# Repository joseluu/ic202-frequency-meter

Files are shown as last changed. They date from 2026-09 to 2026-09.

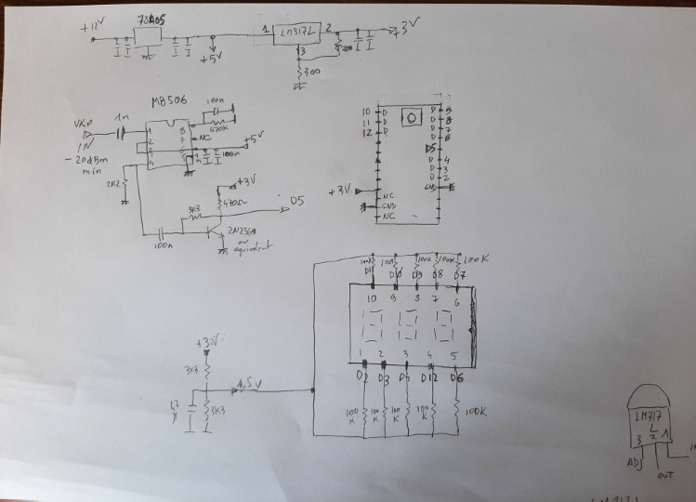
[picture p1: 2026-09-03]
docs/Schema_propre.jpg

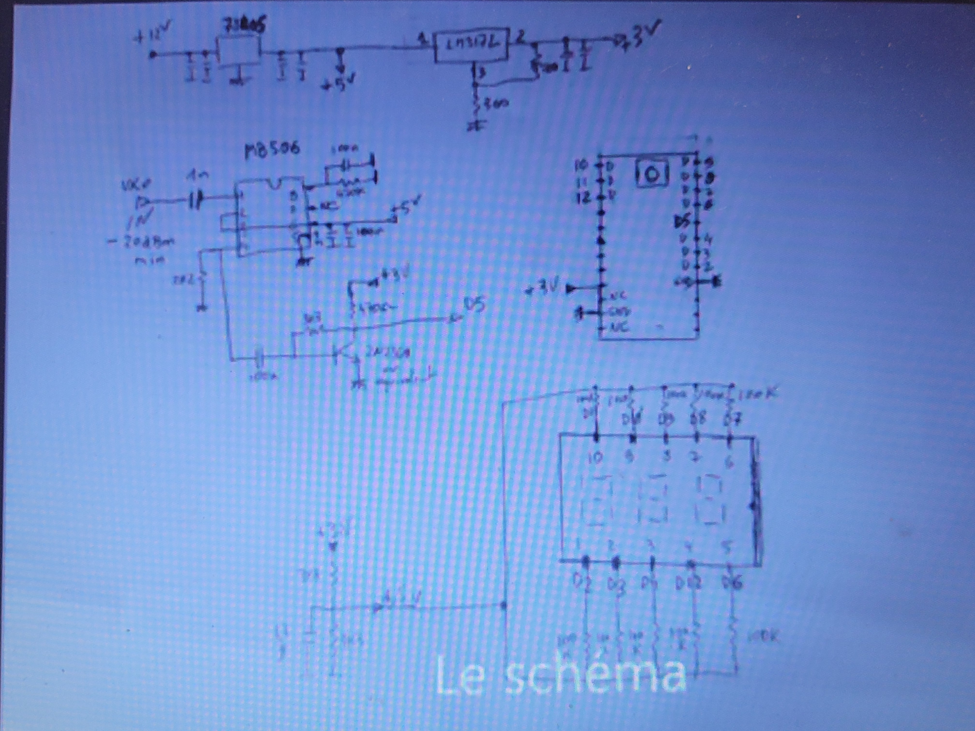
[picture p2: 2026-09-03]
docs/Schema.jpg

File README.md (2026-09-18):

# Fréquencemètre IC-202

Projet KiCad transcrit du schéma manuscrit, selon la description de
`docs/specifications.md`. Deux versions du schéma existent dans `docs/` :
`Schema.jpg`, la première photo, et `Schema_propre.jpg`, une reprise plus
lisible qui a servi à corriger plusieurs valeurs mal lues sur la première.

Chaîne de mesure : entrée RF → prédiviseur MB506 → étage de mise en forme à
transistor alimenté en 3 V → broche D5 d'un Arduino Pro Mini → afficheur LCD
3 digits 7 segments multiplexé, déporté au bout d'une nappe.

## Contenu

| Fichier | Rôle |
|---|---|
| `kicad/ic202-frequencemetre.kicad_pro` | Projet KiCad 10 |
| `kicad/ic202-frequencemetre.kicad_sch` | Schéma (feuille A3 unique) |
| `kicad/ic202-frequencemetre.kicad_pcb` | Carte, encore vide |
| `kicad/IC202.kicad_sym` | Symboles créés pour ce projet |
| `kicad/sym-lib-table` | Enregistrement de la bibliothèque de symboles `IC202` (portée projet) |
| `kicad/frequencemetre.pretty/` | Empreintes créées pour ce projet |
| `kicad/fp-lib-table` | Enregistrement de la bibliothèque d'empreintes `frequencemetre` (portée projet) |
| `kicad/ic202-frequencemetre.pdf` / `.svg` | Schéma exporté |
| `kicad/bom.csv` | Nomenclature |
| `kicad/erc.rpt` | Rapport ERC |
| `docs/Schema.jpg`, `docs/Schema_propre.jpg` | Schéma manuscrit d'origine et sa reprise lisible |
| `docs/LCD.png` | Fiche technique de l'afficheur LCD |

## État de vérification

- ERC : **0 erreur, 0 avertissement**.
- Netlist vérifiée broche à broche par export `kicadxml` après chaque retouche.
- `check_label_rotations.py` et `check_symbol_overlap.py` : OK.
- `lint_offgrid` : aucune coordonnée hors grille 1,27 mm.

## Organisation du schéma

La disposition reprend celle du schéma papier : alimentation en bandeau haut,
prédiviseur à gauche, mise en forme au centre, Arduino à droite, afficheur en
bas à droite. Les liaisons courtes à l'intérieur d'un bloc sont des fils ; les
rails d'alimentation et les signaux entre blocs passent par étiquettes de net.

## Règles de lisibilité appliquées

Les directives du skill
[kicad-schematic-readability](https://github.com/joseluu/kicad-schematic-readability)
sont respectées, et vérifiées par deux scripts locaux au poste de travail :

```
python check_label_rotations.py  .../ic202-frequencemetre.kicad_sch   # OK
python check_symbol_overlap.py   .../ic202-frequencemetre.kicad_sch   # OK
```

- **GND indépendants** : aucun fil de masse ne traverse la feuille, chaque
  composant a son propre stub GND.
- **Alimentation en haut, GND en bas** : les découplages ont leur broche
  positive vers le haut et leur masse vers le bas. Les connecteurs suivent la
  même règle : `J1` porte le +12 V en haut et la masse en bas, `J2` a son
  blindage dirigé vers le bas. Les deux ont été retournés par un miroir, ce qui
  inverse l'ordre des broches sans déplacer la broche de signal.
- **Signaux de gauche à droite** : entrée RF à gauche, progression vers
  l'Arduino puis l'afficheur à droite.
- **Étiquettes réservées aux signaux utiles** : rails, RF_IN, D5_SIG,
  VLCD_MID et les dix lignes LCD_COM/LCD_SEG. SW1 et SW2 sont marquées non
  connectées plutôt qu'étiquetées, faute d'utilité une fois flottantes.
- **Aucun chevauchement de symboles.**

### Placement des repères et valeurs

- **Circuits intégrés rectangulaires** (`U1`, `U2`, `U3`, `A1`, `DS1`) : repère
  et valeur au centre du rectangle, l'intérieur étant libre depuis le masquage
  des noms de broches. Ces champs ne portent aucun `justify`, le défaut centré
  étant celui recherché.
- **Résistances** : valeur au centre du corps et repère sur la ligne au-dessus,
  les deux suivant l'orientation du composant. Pour une résistance verticale le
  texte se lit de bas en haut, donc la ligne au-dessus est celle de gauche.
- **Condensateurs** : repère et valeur de part et d'autre du fil du symbole,
  juste sous les armatures. Le cas vertical exige un `justify` explicite, sinon
  le texte traverse le fil. Le cas horizontal sépare par la hauteur.

### Convention d'orientation des étiquettes

Une étiquette de net a besoin des **deux** informations, et elles doivent être
cohérentes entre elles :

- l'**angle** donne l'axe de lecture, et sert d'indicateur de direction pour le
  script de contrôle ;
- le **`justify`** décide de quel côté du point d'ancrage le texte est posé.
  C'est lui seul que KiCad utilise pour placer le texte.

| Angle | `justify` | Le texte se pose |
|---|---|---|
| 0 | `left bottom` | à droite de l'ancrage |
| 90 | `left bottom` | au-dessus |
| 180 | `right bottom` | à gauche |
| 270 | `right bottom` | en dessous |

Le second mot `bottom` décale le texte perpendiculairement, pour qu'il ne soit
pas posé sur le fil.

**Piège n° 1 : pas de `justify` du tout.** Le défaut de KiCad est *centré*, donc
l'étiquette chevauche son propre point de connexion et le numéro de broche.
C'est visible surtout sur les étiquettes posées directement sur une broche, les
étiquettes en bout de stub ayant de la place autour. Chaque étiquette doit
porter un `justify` explicite.

**Piège n° 2 : `lint_schematic_cosmetic` passe `orient_labels`.** Cette passe du
serveur MCP produit une orientation à 180° de la bonne. Ne pas la relancer sur
ce schéma. Si c'est fait par erreur, réappliquer la table ci-dessus.

**Autre piège.** Dans un champ `property` d'un symbole tourné à 90°, l'angle
est relatif au symbole : il faut écrire 270 pour obtenir un texte horizontal.
C'est le cas des repères de `R7`..`R16`.

### Alimentation

`J1` (+12 V) → `U1` AMS1117-5.0 → +5 V → `U2` AMS1117 (ADJ) → +3 V.
Découplage 100 nF + 10 µF sur chacun des trois rails.

Les deux régulateurs sont en boîtier CMS SOT-223, choisis dans le stock
PartsBox de l'utilisateur plutôt que les L7805/LM317L d'origine (traversants,
non tenus en stock CMS) : mêmes coordonnées de broches, seule leur
numérotation change. Sur `U1`, l'entrée devient la broche 3 (VI) et la
sortie la broche 2 (VO) — sur `U2`, `1`=ADJ, `2`=VO, `3`=VI comme
auparavant, l'architecture (référence 1,25 V, pont diviseur) étant la même
famille que le LM317.

Le +3 V est réglé par `R1` (220 R, VO→ADJ de `U2`) et `R2` (300 R,
ADJ→GND) :

    Vout = 1,25 x (1 + 300/220) = 2,95 V

C'est proche de la tension de service du LCD (3,0 V), indiquée sur sa fiche.
Ce pont n'a pas changé de valeur : l'AMS1117 ajustable utilise la même
référence 1,25 V que le LM317L qu'il remplace.

`#FLG01` et `#FLG02` sont les PWR_FLAG des rails +12 V et GND, qui ne sont
alimentés que par un connecteur.

`J1` est un connecteur 4 broches (header 2,54 mm) : les broches 1 et 2,
adjacentes, portent toutes deux le +12 V ; les broches 3 et 4, adjacentes,
portent toutes deux le GND. Le doublement de chaque broche répartit le
courant d'alimentation sur deux points de contact.

### Prédiviseur MB506

`U3` est le Fujitsu **MB506PF**, boîtier CMS SOP-8 (208 mil, empreinte
`Package_SO:SOIC-8_5.3x6.2mm_P1.27mm`), en remplacement du MB506 traversant
DIP-8 d'origine — même brochage 1-8 (IN, VCC, SW1, OUT, GND, SW2, NC, /IN),
choisi dans le stock PartsBox de l'utilisateur.

- `J2` entrée RF, terminaison `R3` 51 R, liaison capacitive `C7` 1 nF vers IN (broche 1).
  Pas de connecteur SMA monté : un mini câble coaxial est soudé directement
  sur deux pastilles (`TestPoint:TestPoint_2Pads_Pitch2.54mm_Drill0.8mm`,
  pas 2,54 mm, perçage 0,8 mm) — âme sur la pastille 1 (IN), blindage sur
  la pastille 2 (GND).
- Entrée complémentaire /IN (broche 8) : découplée à la masse par `C8` 100 nF,
  et polarisée par `R20` 470 kΩ vers GND. C'est le réseau optionnel repéré sur
  le schéma relu (voir « Hypothèses de transcription ») ; il fixe le point de
  repos de l'entrée complémentaire quand le MB506 est piloté en simple
  extrémité (un seul signal sur IN, ~IN laissée au repos).
- VCC (broche 2) en +5 V, découplé par `C9` 100 nF.
- Sortie OUT (broche 4) : pull-down `R19` (2K2) vers GND, en parallèle de la
  liaison capacitive vers l'étage de mise en forme. C'est une terminaison
  usuelle pour une sortie de type collecteur ouvert / ECL.
- Broche 7 (NC) marquée non connectée. La datasheet Fujitsu ne lui donne
  aucune fonction : le rapport de division est fixé uniquement par SW1 et
  SW2, il n'y a pas de troisième entrée de sélection.
- SW1 (broche 3) et SW2 (broche 6) reliées au rail +5 V **à travers un
  cavalier à souder fermé** (`JP11` sur `MB506_SW1`, `JP12` sur `MB506_SW2`,
  empreinte `Jumper:SolderJumper-2_P1.3mm_Bridged_Pad1.0x1.5mm`).

D'après la table du constructeur (H = VCC, L = ouvert), SW1 et SW2 au niveau H
donnent le rapport **1/64**, comportement par défaut de cette carte :

| SW1 | SW2 | Division |
|---|---|---|
| ouvert | ouvert | 1/256 |
| ouvert | +5 V | 1/128 |
| +5 V | ouvert | 1/128 |
| **+5 V** | **+5 V** | **1/64** |

Le schéma d'origine prévoyait un connecteur `J3` pour choisir le rapport ; il
n'apparaît plus sur le schéma relu, qui laisse SW1/SW2 flottants (1/256 par
défaut). À la demande explicite, les deux broches sont ici reliées au +5 V
pour fixer la division à 1/64. `JP11`/`JP12` remplacent ce sélecteur : livrés
fermés, ils conservent le 1/64 ; couper `JP11` **ou** `JP12` au cutter remet
la broche correspondante en l'air (niveau L) et donne 1/128, couper les deux
donne 1/256. Un coup de fer à souder revient en arrière.

### Mise en forme vers D5

`Q1` est le NPN RF **2SC5551AE-TD-E** (onsemi), boîtier CMS SOT-89
(30 V, 300 mA, fT = 3,5 GHz), en remplacement du 2N2369 traversant (TO-18,
fT ≈ 500 MHz) — choisi dans le stock PartsBox de l'utilisateur, largement
assez rapide pour ce rôle. Le brochage réel (1 = base, 2 = collecteur sur
la languette, 3 = émetteur) ne correspond pas à l'ordre du symbole générique
KiCad `Q_NPN_BEC` (broche 2 = émetteur, broche 3 = collecteur) : le symbole a
donc été remplacé par `Q_NPN_BCE` (broche 2 = collecteur, broche 3 =
émetteur), qui a la même géométrie de broches — seul l'étiquetage
broche/fonction change, le câblage existant reste intact — pour que la
numérotation corresponde à celle de l'empreinte SOT-89.

Sortie ECL du MB506 → `C10` 100 nF → base de `Q1`. `R4` 3,3 kΩ relie
la base au collecteur (contre-réaction continue, pas une résistance série vers
la masse comme dans une première version du schéma). Émetteur à la masse,
collecteur tiré au +3 V par `R6` 470 Ω, et c'est ce nœud collecteur qui attaque
D5. Le point de repos de `Q1` s'auto-régule par cette contre-réaction plutôt
que par un pont de base classique. Le niveau logique vu par l'Arduino est donc
bien du 3 V, d'où la présence du second régulateur (`U2`).

### Arduino

L'Arduino Pro Mini est la version **3,3 V / 8 MHz**, alimentée sur sa broche VCC
depuis le rail +3 V (le régulateur de la carte est contourné, RAW non connectée).
L'ATmega328P à 8 MHz fonctionne sans réserve jusqu'à 2,7 V.

D13 est laissé libre à cause de la LED intégrée. TXO/RXI restent disponibles
pour la programmation par le connecteur FTDI de la carte.

**Montage sur picots.** Le Pro Mini n'est pas soudé directement : il se
branche sur deux barrettes de picots femelles soudées sur le PCB principal
(empreinte `frequencemetre:Arduino_Pro_Mini_Header_2x12`). Il se trouve donc surélevé
par rapport à la carte, et le volume dégagé en dessous est disponible pour
d'autres composants. Cette empreinte ne modélise que les deux courtyards des
barrettes (pas de contour de carte complet ni de courtyard unique englobant
tout le module), justement pour ne pas signaler ce volume comme occupé.

Géométrie vérifiée contre l'empreinte open source
[`Arduino_Pro_Mini_Socket`](https://github.com/Alarm-Siren/arduino-kicad-library)
(2 rangées de 12 broches au pas de 2,54 mm, 15,24 mm entre rangées) : 24
broches au total, pas de connecteur de programmation FTDI modélisé. Les
broches A4/SDA et A5/SCL du Pro Mini réel ne sont pas sur ces barrettes — ce
sont des pastilles au dos du module, atteignables seulement par un fil volant
— et ont été retirées du symbole `IC202:Arduino_Pro_Mini`, qui ne comptait
d'ailleurs déjà aucune connexion sur ces deux broches.

### Afficheur LCD

`docs/LCD.png` donne la fiche du composant :

| Caractéristique | Valeur |
|---|---|
| Technologie | TN, polariseur réflectif positif |
| Multiplexage | 1/4 duty, 1/2 bias |
| Tension de service | 3,0 V |
| Angle de lecture | 6 heures |
| Broches | 10, au pas de 2,00 mm |

Référence commerciale :
<https://fr.aliexpress.com/item/1005003745628043.html>

Le 1/4 duty impose **4 communs**, et les 10 broches se répartissent donc en
4 communs plus **6 segments**. Cela adresse 4 × 6 = 24 segments, dont 21 pour
les trois chiffres.

C'est un afficheur à cristaux liquides : il ne consomme aucun courant et ne
supporte pas de tension continue permanente, qui le détruirait par
électrolyse. Il n'y a donc **pas de résistance de limitation** ; l'attaque se
fait en alternatif, par inversion de polarité à chaque trame.

**Attaque en 1/2 bias par tri-état.** Chaque ligne a besoin de trois niveaux :
0 V, 1,5 V et 3 V. Les broches de l'Arduino en fournissent deux, et le
troisième vient de la mise en haute impédance : la ligne rejoint alors la
référence à mi-tension `VLCD_MID` à travers sa résistance de 100 kΩ.

| Élément | Rôle |
|---|---|
| `R7`..`R16` (100 kΩ) | une par ligne, vers `VLCD_MID` |
| `R17`, `R18` (10 kΩ) | pont générant `VLCD_MID` = 3 V / 2 |
| `C12` (1 µF) | découplage de la référence |

Le pont est dix fois plus raide que les résistances de ligne, pour que la
référence ne bouge pas quand plusieurs broches commutent.

**Cavaliers de coupure devant `J4`.** Un cavalier à souder fermé par défaut
(`JP1`..`JP10`, empreinte `Jumper:SolderJumper-2_P1.3mm_Bridged_Pad1.0x1.5mm`)
est inséré en série entre chaque ligne (`R7`..`R16`) et sa broche de `J4` —
un par ligne LCD. Chaque ligne passe donc par deux nœuds électriques
distincts : le nœud côté Arduino/résistance (nom de net inchangé,
`LCD_COM1`..`LCD_SEG6`) et le nœud côté `J4` (nommé explicitement
`J4_COM1`..`J4_SEG6`), reliés par le cavalier. Fermés (comportement par
défaut, pont de cuivre déjà présent sur l'empreinte), la liaison vers la
nappe LCD est normale ; les couper au cutter isole la carte de la nappe —
utile pour tester l'étage Arduino/résistances seul avant de raccorder
l'afficheur. Un coup de fer à souder rétablit ensuite la liaison.

**Deux bugs de câblage trouvés et corrigés après coup, à l'occasion d'une
tentative de routage** (voir plus bas) :

1. Les 10 fils reliant chaque cavalier à sa broche de `J4` passaient par un
   point de coude intermédiaire à une abscisse commune (`x=330.2`) pour
   rester orthogonaux. Plusieurs de ces segments verticaux se chevauchaient
   partiellement sur cette même abscisse (les nappes de lignes LCD ont des
   pas différents côté résistances — 5,08 mm — et côté `J4` — 2,54 mm — donc
   leurs coudes intermédiaires ne tombent pas aux mêmes hauteurs), ce qui a
   **court-circuité entre elles plusieurs lignes LCD** (`COM2`-`COM3`-`COM4`-`SEG1`
   d'un côté, `SEG3`-`SEG4` de l'autre). L'ERC ne signalait qu'un avertissement
   discret (« multiple_net_names »), pas une erreur — c'est une relecture du
   netlist exporté par `kicad-cli` (source de vérité) qui a révélé l'ampleur
   réelle du problème. Corrigé en remplaçant les 10 chemins coudés par un
   fil diagonal unique par ligne (pas de point partagé entre lignes
   différentes, donc aucun risque de chevauchement accidentel).
2. Après correction du point 1, le nom de net explicite (`J4_COM1` etc.) a
   dû être ajouté sur chaque broche de `J4` : sans lui, `sync_schematic_to_board`
   (l'outil MCP qui importe le schéma dans le PCB) n'arrivait pas à
   résoudre les nets anonymes auto-générés par KiCad (`Net-(J4-Pin_X)`) et
   laissait ces broches et celles des cavaliers **sans net du tout** côté
   PCB — invisibles pour le ratsnest et l'autorouteur, silencieusement, sans
   qu'aucun outil ne le signale comme une erreur. Un nom de net explicite
   sur chaque broche contourne cette limite.

**Affectation des broches de l'Arduino :**

| Broche | Ligne LCD |
|---|---|
| D5 | entrée de comptage depuis l'étage transistor |
| D2, D3, D4, D6 | COM1, COM2, COM3, COM4 |
| D7, D8, D9, D10, D11, D12 | SEG1 à SEG6 |

**Liaison par nappe.** Le LCD est déporté au bout d'une nappe de 10
conducteurs. `J4` (header mâle au pas de 2,54 mm) est le seul connecteur
présent sur la carte ; `DS1`, l'afficheur, n'est **pas monté sur ce PCB**,
il se trouve à l'autre extrémité du câble. Le symbole `DS1` est marqué
« hors carte » (`on_board: no`) : il reste dans le schéma et la nomenclature
pour documenter le système complet, mais `sync_schematic_to_board` ne lui
crée pas d'empreinte sur cette carte.

## Intention de conception pour le placement/routage

Le schéma porte, en plus de la connectivité, une propriété masquée
`Placement` sur chaque composant dont la position physique finale importe
au-delà du simple raccordement électrique — suivant le skill Claude Code
`conception-electronique-kicad`. Cette propriété n'apparaît pas sur le
schéma ; elle se lit via `get_schematic_component` ou en filtrant le
`.kicad_sch` sur `(property "Placement"`. **Elle ne s'applique pas toute
seule** : au moment du placement/routage, il faut demander explicitement de
la respecter.

**Découplage documenté** (préfixe `LOCAL`) :

| Réf. | Rôle |
|---|---|
| `C1`, `C2` | HF / bulk BF, entrée `J1` et broche 3 (VI) de `U1` |
| `C3`, `C4` | HF / bulk BF, nœud +5 V partagé broche 2 (VO) de `U1` / broche 3 (VI) de `U2` |
| `C5`, `C6` | HF / bulk BF, broche VO (sortie) de `U2` |
| `C9` | HF, broche VCC de `U3` |
| `C8` | HF de la broche ~IN (signal, pas alimentation) de `U3`, avec `R20` |
| `C11` | HF du rail +3 V près de `R6`, point le plus éloigné de `U2` |
| `C12` | référence `VLCD_MID`, point milieu du pont `R17`/`R18` |

Vérification faite : les trois circuits intégrés actifs (`U1`, `U2`, `U3`)
ont chacun un découplage local documenté sur leur(s) broche(s)
d'alimentation. `A1` (Arduino Pro Mini) n'est pas inclus dans cette
vérification : c'est un module complet avec son propre découplage embarqué,
pas un CI nu à décrire ici.

**Boucles critiques documentées** (préfixe `LOOP CRITIQUE`, hors
découplage) :

- `J2`-`R3`-`C7` → broche IN de `U3` : chemin RF d'entrée, jusqu'à 2,4 GHz,
  surface minimale impérative.
- `U3`(OUT)-`R19`-`C10`-`R4`-`R6`-`Q1` → `D5_SIG` (broche D5 de `A1`) : chemin
  de comptage, le signal que l'instrument existe pour mesurer — à éloigner
  des sources de bruit.

### Placement initial (fait)

Carte **80 × 50 mm**, paysage (hauteur réduite de 70 à 50 mm après le
passage aux boîtiers CMS ci-dessous, qui a libéré de la place). Emplacements
imposés par l'utilisateur :

- `J1` (+12 V IN) : bord haut, au milieu, rangée de broches **parallèle**
  au bord (rotation 90° par rapport à l'orientation par défaut du
  footprint, qui les mettait perpendiculaires).
- `J2` (RF IN, coax à souder) : bord gauche, rangée de broches parallèle au
  bord (même correction de rotation).
- `J4` (nappe LCD, header 2,54 mm) : bord droit.
- `A1` (Arduino Pro Mini sur picots) : décalé de 3 mm vers la gauche par
  rapport au premier placement, toujours à droite et proche de `J4`,
  orientation paysage, extrémité USB/FTDI côté gauche (rotation 90°, vérifiée
  par la mesure des pads comme au premier placement).
- `R7`..`R16` (échelle de polarisation LCD) : **sous `A1`**, dans le volume
  dégagé entre les deux barrettes de picots — l'empreinte de `A1` ne porte
  que les deux courtyards des barrettes (voir « Arduino » ci-dessus), donc
  cet espace n'est pas signalé occupé.

L'orientation « parallèle au bord le plus proche » pour `J1`/`J2` est
désormais une règle par défaut du skill `kicad-pcb-placement` : elle
s'applique à tout connecteur proche d'un bord, sauf orientation contraire
explicitement demandée.

Le reste (bloc d'alimentation, chaîne RF/prédiviseur, chemin de comptage,
cavaliers `JP1`-`JP10`, `R17`/`R18`/`C12`) est réparti par proximité en
suivant les groupes `Placement` du schéma. Vérifié via `run_drc`
(kicad-cli, source de vérité du projet) : **0 erreur**, 3 avertissements
cosmétiques silkscreen. Méthode suivie : skill Claude Code
`kicad-pcb-placement`.

### Routage (fait)

Autoroutage via Freerouting (`autoroute`, 2 couches F.Cu/B.Cu) sur ce
placement : **16,5 s**, 278 pistes + 29 vias. Deux passes de nettoyage
après coup :

- 11 pistes exportées à 0,15 mm par le pipeline KiCad→DSN→Freerouting alors
  que la carte impose 0,2 mm minimum (limite connue de ce pipeline,
  reproductible même en relançant l'autoroutage plusieurs fois de suite —
  ne se corrige pas tout seul). Corrigées une par une : piste supprimée puis
  retracée au même endroit avec une largeur explicite de 0,2 mm.
- Un essai de placement alternatif via l'outil externe **FD-Autoplacer**
  (`github.com/joseluu/FD-Autoplacer`, optimisation par descente de
  gradient) a été comparé sur ce même schéma : passage clone → exécution →
  import direct, sans succès retenu (chevauchement de courtyard réel,
  plusieurs composants débordant du bord de carte) — le placement à la main
  ci-dessus a été conservé.

Résultat final vérifié via `run_drc` : **0 erreur**, 10 avertissements
cosmétiques (7 vias non connectées des deux côtés, 1 chevauchement
silkscreen, 2 silkscreen sur cuivre).

### Bug critique trouvé et corrigé après coup : broches actives sans net

En inspectant le PCB routé, une broche visiblement connectée à trop
d'endroits (broche 1 de `U3`) a révélé un bug bien plus large : **5 nets
sans label explicite** (`Net-(U3-IN)`, `Net-(U3-OUT)`, `Net-(U3-~{IN})`,
`Net-(Q1-B)`, `Net-(U2-ADJ)`) — électriquement valides au niveau du schéma,
l'ERC ne signale rien — mais que `sync_schematic_to_board` échoue à
résoudre silencieusement, laissant les broches concernées **sans net du
tout côté PCB**. Conséquence réelle : la sortie du prescaler (`U3` OUT) et
la base de `Q1` n'ont jamais été reliées à la chaîne de comptage, sur les
deux cartes, malgré un DRC à 0 erreur — une broche sans net n'ayant par
ailleurs aucune obligation de clearance, ce qui explique l'apparence de
connexion multiple constatée.

Corrigé : les 5 nets renommés explicitement (`MB506_IN`, `MB506_OUT`,
`MB506_NIN`, `Q1_BASE`, `U2_ADJ`), resynchronisés vers les deux PCB, la
règle de clearance globale remontée de 0 mm (!) à 0,2 mm — qui a d'ailleurs
mis au jour des croisements de pistes que le clearance nul masquait — puis
carte principale entièrement reroutée : **0 erreur `run_drc`** au final
(327 pistes, 40 vias, même limite de 0,15 mm sur quelques pistes corrigée
comme précédemment). Règle ajoutée au skill `conception-electronique-kicad`
pour détecter ce cas systématiquement avant tout premier routage.

**Piège outil découvert à cette occasion :** `check_courtyard_overlaps`
(MCP) évalue le chevauchement de courtyard d'une empreinte à partir de sa
*bounding box globale*, pas des polygones réels — pour une empreinte à
plusieurs rectangles de courtyard disjoints comme celle de `A1` (justement
conçue pour laisser un volume libre au milieu), l'outil signale à tort un
chevauchement dès qu'un autre composant entre dans cette bounding box, y
compris pile au centre du volume libre. Vérifié en plaçant une résistance
au centre exact de `A1` et en comparant : `check_courtyard_overlaps` la
signale en conflit, `run_drc` (qui lit les vrais polygones KiCad) ne
signale rien. Pour toute empreinte de ce genre, se fier à `run_drc`, pas à
`check_courtyard_overlaps`.

## Hypothèses de transcription

La photo du schéma manuscrit n'est pas assez nette pour toutes les annotations.
Les points suivants ont été déduits ; ils sont à confronter à l'original.

| Élément | Retenu | Raison |
|---|---|---|
| `Q1` | 2N2369 | Lecture la plus probable de l'annotation ; transistor de commutation rapide cohérent avec l'usage. Tout NPN rapide équivalent convient. |
| `R17`, `R18` | 3,3 kΩ chacune | Valeur clairement lisible sur le schéma relu. |
| Affectation des 10 broches de `DS1` | 1..4 = COM1..COM4, 5..10 = SEG1..SEG6 | La fiche donne le nombre de broches et le multiplexage, pas leur ordre. **À confirmer avant fabrication.** |

Le schéma manuscrit relu (`docs/Schema_propre.jpg`) est nettement plus lisible
que la première photo et a permis de corriger plusieurs valeurs mal lues, ainsi
que d'ajouter des composants absents de la première transcription. Le tableau
ci-dessous liste les changements :

| Élément | Ancienne valeur | Valeur corrigée |
|---|---|---|
| `R1` | 100 R | 220 R |
| `R2` | 160 R | 300 R |
| `R6` | 1 k | 470 R |
| `C8` | 1 n | 100 n |
| `R17`, `R18` | 10 k | 3,3 k |
| ancien `R5` (100 k, base→GND) | présent | supprimé, absent du schéma relu |
| ancien `J3` (sélecteur SW1/SW2) | présent | supprimé, remplacé par les cavaliers `JP11`/`JP12` (fermés = 1/64) |
| `R19` (2K2, OUT MB506→GND) | absent | ajouté |
| `R4` | 1 k, en série cap→base | 3,3 k, en contre-réaction base→collecteur |
| `R20` (470 kΩ, broche 8 ~IN→GND) | absent | ajouté |

Deux de ces corrections ont été apportées directement dans KiCad par
l'utilisateur puis relues par la suite : le rebranchement de `R4` en
contre-réaction base→collecteur (la première transcription le plaçait par
erreur en série entre `C10` et la base), et l'ajout de `R20`, le réseau
repéré près de la broche complémentaire (~IN, broche 8) du MB506, qui polarise
cette broche vers la masse quand le composant est piloté en entrée simple.

## Ce qui reste à faire

1. **Obtenir la table de correspondance segments du LCD**, c'est-à-dire quel
   couple (COM, SEG) allume quel segment de quel chiffre. Elle n'est pas dans
   la fiche et conditionne le firmware. Sans elle, on peut router la carte mais
   pas afficher un chiffre juste.
2. **Confirmer l'affectation des 10 broches** en communs et segments.
3. **Empreinte de `A1`.** `DS1` n'a pas besoin d'empreinte, il n'est pas
   monté sur ce PCB (voir « Afficheur LCD »). `J4` est un header 1×10 au
   pas de 2,54 mm (`Connector_PinHeader_2.54mm:
   PinHeader_1x10_P2.54mm_Vertical`).
4. **Confirmer les valeurs du tableau d'hypothèses** sur le schéma d'origine.
5. ~~Routage de la carte~~ — fait (voir « Routage » ci-dessus), 0 erreur DRC.
6. **Firmware.** Comptage sur D5, division par 256 à compenser, puis génération
   des trames LCD en 1/4 duty et 1/2 bias : chaque broche prend tour à tour
   l'état haut, bas ou haute impédance, et la polarité s'inverse à chaque trame
   pour que la tension moyenne sur chaque segment reste nulle.

## Ouvrir le projet

```
"C:/Program Files/KiCad/10.0/bin/kicad.exe" kicad/ic202-frequencemetre.kicad_pro
```

La bibliothèque `IC202` est enregistrée en portée projet ; elle est trouvée
automatiquement à l'ouverture.

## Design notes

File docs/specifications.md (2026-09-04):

Utilise kicad-mcp pour creer le projet ic202-frequencemetre. Crée le schema a partir de doc/schema.jpg. Description du circuit: alimentation 12V, regulateur 5V puis 3.3V. Prédiviseur MB506 suivi d'un etage a transistor alimenté en 3.3V qui pilote la broche D5 d'un arduino pro mini, le arduino pro mini pilote un affichage LCD 3 digit 7 segments multiplexé.

## modification 1
Erreur dans l'enoncé, c'est du 3V et non du 3.3V. Un information sur le LCD est dans doc/LCD.png une URL decrivant le LCD est https://fr.aliexpress.com/item/1005003745628043.html, le LCD est à l'extremité d'une nappe de fils, representer les connecteurs sur le schema.

## modification 2
Relis le schema en principe plus lisible dans doc/schema_propre.jpg et corrige le schema kicad si necessaire.

## alternative envisagee (non retenue pour l'instant) : remplacer le Arduino Pro Mini
Objectif : reduire l'encombrement de la carte. Le Pro Mini (33 x 18 mm) est
plus grand que necessaire pour ce projet, qui n'a besoin que de 11 broches
(D5 + 10 lignes LCD COM/SEG en tri-etat).

Le ESP32-C3-SuperMini a ete ecarte : seulement 11 GPIO exploitables au total,
dont 2 broches de strapping (GPIO8/9), soit une marge nulle pour les 11
broches necessaires.

Meilleure alternative identifiee : **ESP32-C3-MINI-1U** (module Espressif nu,
a souder directement, sans antenne PCB integree - remplacee par un connecteur
U.FL/IPEX laisse non connecte puisque ce projet n'utilise ni WiFi ni
Bluetooth) :
- Dimensions : 13,2 x 12,5 mm (~165 mm^2), contre 13,2 x 16,6 mm pour la
  variante MINI-1 a antenne PCB integree (~219 mm^2), et 33 x 18 mm pour le
  Pro Mini (~594 mm^2).
- 15 GPIO sorties au total (GPIO0-10, 18-21) ; 13 disponibles en gardant
  GPIO18/19 (USB natif) reserves a la programmation - large marge pour les
  11 broches necessaires.
- GPIO4/5/6/7/10 (noms "FSPI...") sont le peripherique SPI generaliste du
  composant, pas le bus interne de la flash embarquee : entierement libres.
- USB natif (USB-Serial-JTAG sur GPIO18/19) : pas de puce FTDI/CH340 a
  ajouter pour la programmation.
- Alimentation 3,0-3,6 V, compatible avec le rail +3 V deja present sur
  cette carte.
- Sans antenne sur le module, pas de zone de degagement RF a respecter sous
  le composant lors du routage.
- Source : datasheet officiel Espressif "ESP32-C3-MINI-1 & MINI-1U
  Datasheet" v2.2 (documentation.espressif.com).

Decision : conserver le Arduino Pro Mini pour l'instant. A reconsiderer si
la reduction de taille devient prioritaire ; impliquerait de changer
d'ecosysteme firmware (Arduino AVR -> Arduino-ESP32 / ESP-IDF) et de
concevoir un symbole/empreinte KiCad pour ce module.

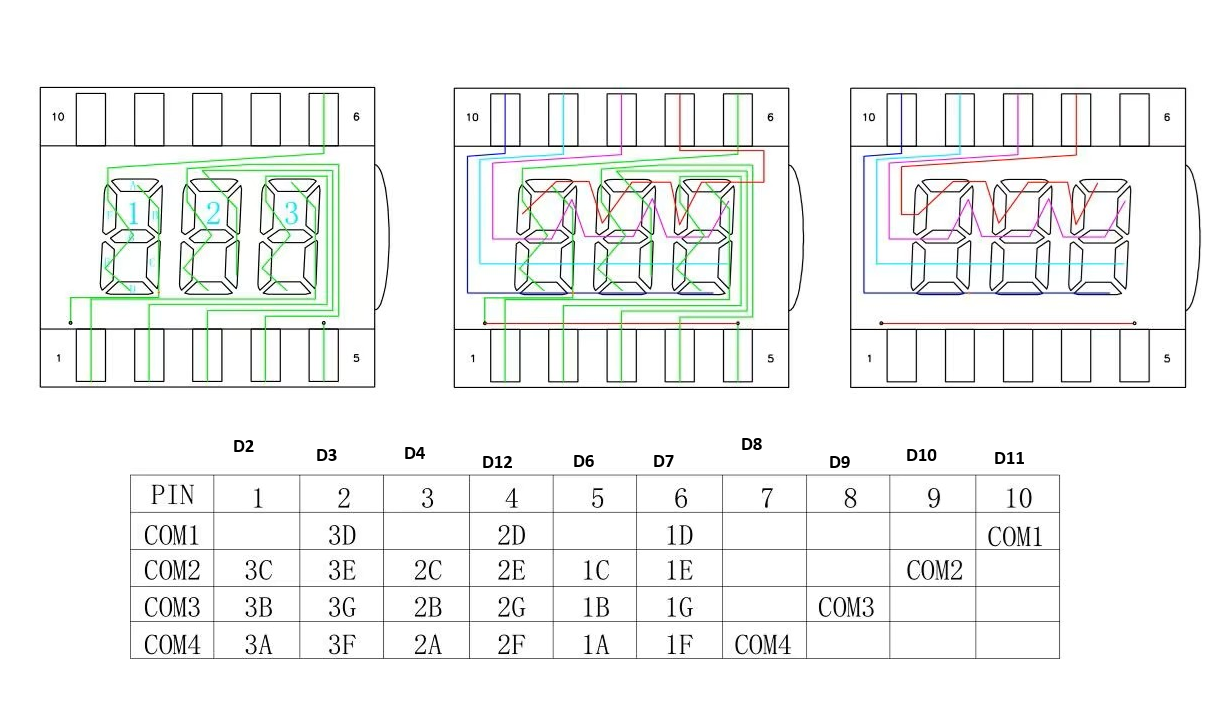
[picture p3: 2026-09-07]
docs/LCD_2.png

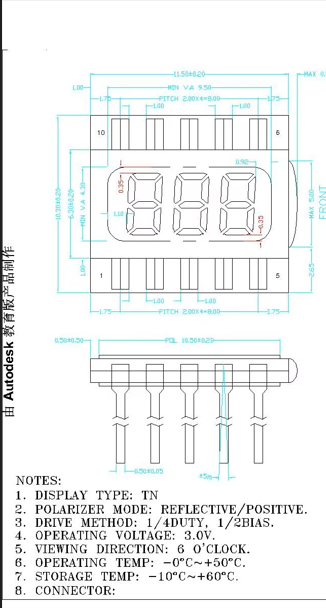
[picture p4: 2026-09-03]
docs/LCD.png

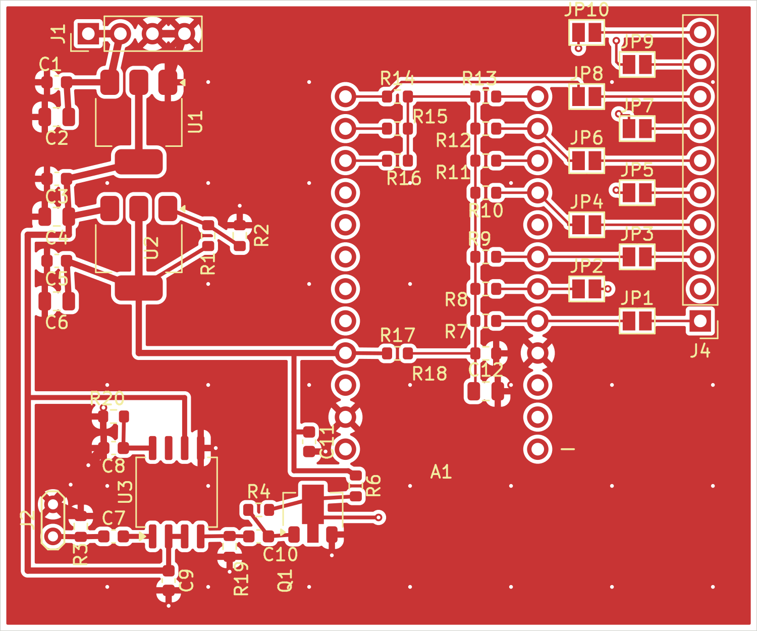
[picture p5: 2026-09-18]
kicad/ic202-frequencemetre_2d_view.png

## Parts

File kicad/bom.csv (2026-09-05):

Reference | Value | Footprint | Description
A1 | Pro Mini 3V3/8MHz | frequencemetre:Arduino_Pro_Mini_Header_2x12 | Arduino Pro Mini module (ATmega328P), 2x12 pin headers. A4/SDA et A5/SCL (broches arriere, non alignees sur les headers) omises : non utilisees dans ce projet.
C1,C3,C5,C8-C11 | 100n | Capacitor_SMD:C_0603_1608Metric | Unpolarized capacitor
C2,C4,C6 | 10u | Capacitor_SMD:C_0805_2012Metric | Unpolarized capacitor
C7 | 1n | Capacitor_SMD:C_0603_1608Metric | Unpolarized capacitor
C12 | 1u | Capacitor_SMD:C_0805_2012Metric | Unpolarized capacitor
DS1 | LCD 3 digits TN |  | Afficheur LCD TN 3 digits 7 segments, 10 broches, multiplexe 1/4 duty 1/2 bias, 3.0V. Repartition COM/SEG a confirmer aupres du fournisseur.
J1 | +12V IN (4 pins: 2x+12V, 2x GND) | Connector_PinHeader_2.54mm:PinHeader_1x04_P2.54mm_Vertical | Connecteur 4 pins, paires adjacentes : pins 1-2 = +12V, pins 3-4 = GND
J2 | RF IN | TestPoint:TestPoint_2Pads_Pitch2.54mm_Drill0.8mm | coaxial connector (BNC, SMA, SMB, SMC, Cinch/RCA, LEMO, ...)
J4 | LCD | Connector_PinHeader_2.54mm:PinHeader_1x10_P2.54mm_Vertical | Generic connector, single row, 01x10, script generated (kicad-library-utils/schlib/autogen/connector/)
JP1-JP10 | SolderJumper_2_Open | Jumper:SolderJumper-2_P1.3mm_Open_Pad1.0x1.5mm | Solder Jumper, 2-pole, open
Q1 | 2SC5551AE-TD-E | Package_TO_SOT_SMD:SOT-89-3 | onsemi 2SC5551A, NPN RF transistor 30V 300mA fT=3.5GHz, SOT-89 (pin1=B, pin2/tab=C, pin3=E)
R1 | 220R | Resistor_SMD:R_0603_1608Metric | Resistor
R2 | 300R | Resistor_SMD:R_0603_1608Metric | Resistor
R3 | 51R | Resistor_SMD:R_0603_1608Metric | Resistor
R4,R17,R18 | 3k3 | Resistor_SMD:R_0603_1608Metric | Resistor
R6 | 470R | Resistor_SMD:R_0603_1608Metric | Resistor
R7-R16 | 100k | Resistor_SMD:R_0603_1608Metric | Resistor
R19 | 2K2 | Resistor_SMD:R_0603_1608Metric | Resistor
R20 | 470K | Resistor_SMD:R_0603_1608Metric | Resistor
U1 | AMS1117-5.0 | Package_TO_SOT_SMD:SOT-223-3_TabPin2 | 1A LDO regulator, fixed output 5.0V, SOT-223
U2 | AMS1117 (ADJ) | Package_TO_SOT_SMD:SOT-223-3_TabPin2 | 1A LDO regulator, adjustable output, SOT-223
U3 | MB506 | Package_SO:SOIC-8_5.3x6.2mm_P1.27mm | Fujitsu MB506PF ultra high frequency prescaler, 2.4 GHz, divide by 64/128/256, SOP-8 (208mil)

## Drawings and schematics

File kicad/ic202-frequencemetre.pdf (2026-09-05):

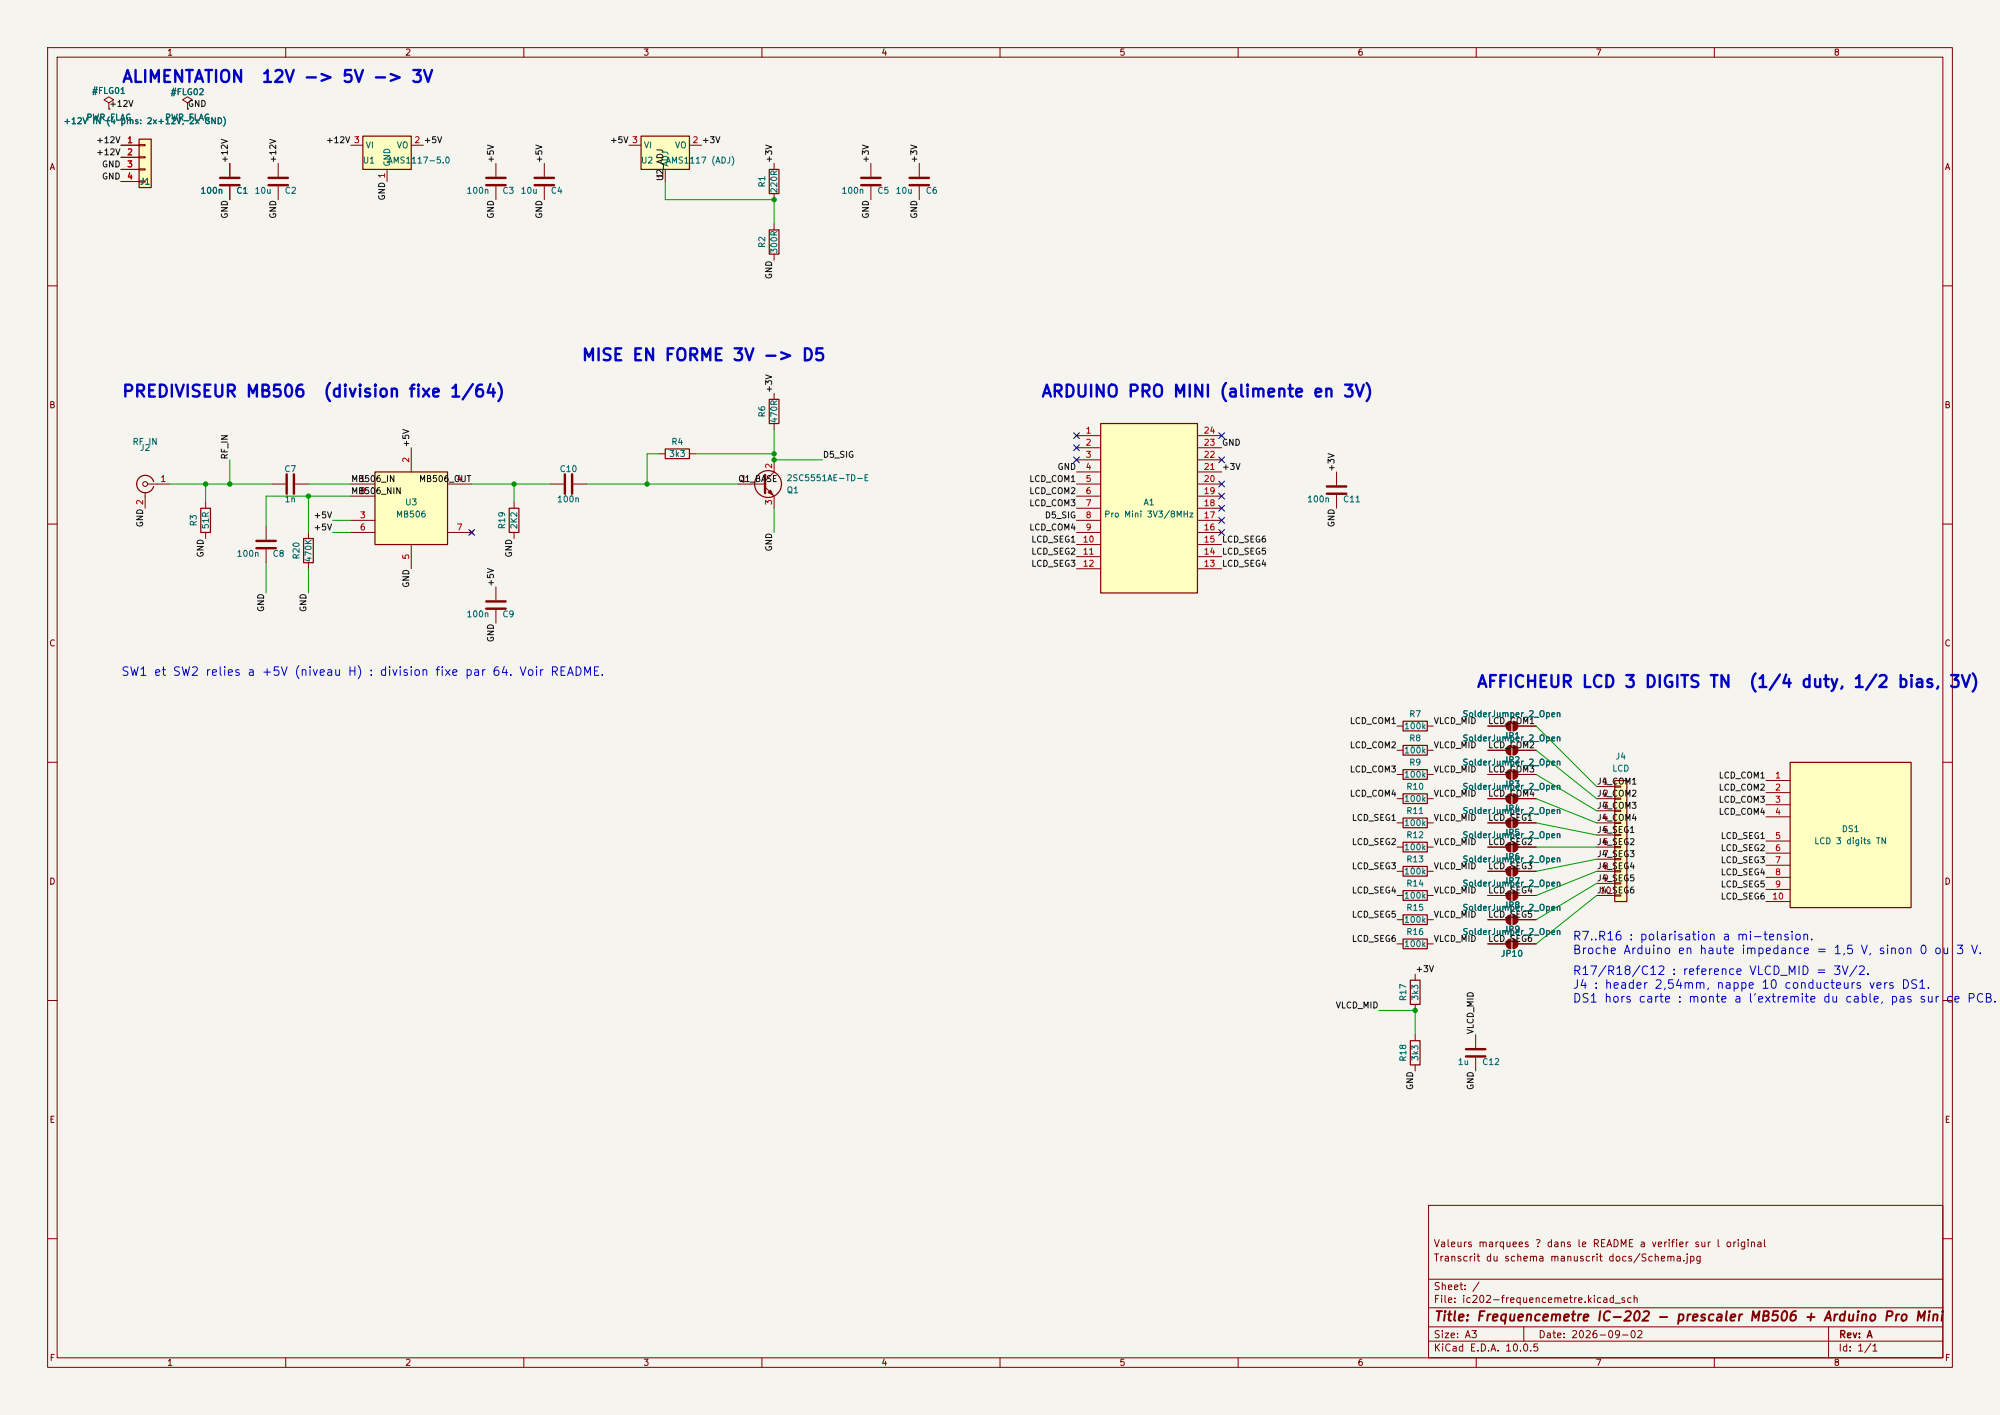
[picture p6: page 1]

ARDUINO PRO MINI (alimente en 3V)

SW1 et SW2 relies a +5V (niveau H) : division fixe par 64. Voir README.

AFFICHEUR LCD 3 DIGITS TN (1/4 duty, 1/2 bias, 3V)

R7..R16 : polarisation a mi-tension.
Broche Arduino en haute impedance = 1,5 V, sinon 0 ou 3 V.
R17/R18/C12 : reference VLCD_MID = 3V/2.
J4 : header 2,54mm, nappe 10 conducteurs vers DS1.
DS1 hors carte : monte a l'extremite du cable, pas sur ce PCB.

Transcrit du schema manuscrit docs/Schema.jpg

Sheet: /
File: ic202-frequencemetre.kicad_sch
Title: Frequencemetre IC-202 - prescaler MB506 + Arduino Pro Mini

Size: A3 | Rev: A | F Date: 2026-09-02
KiCad E.D.A. 10.0.5 | Id: 1/1

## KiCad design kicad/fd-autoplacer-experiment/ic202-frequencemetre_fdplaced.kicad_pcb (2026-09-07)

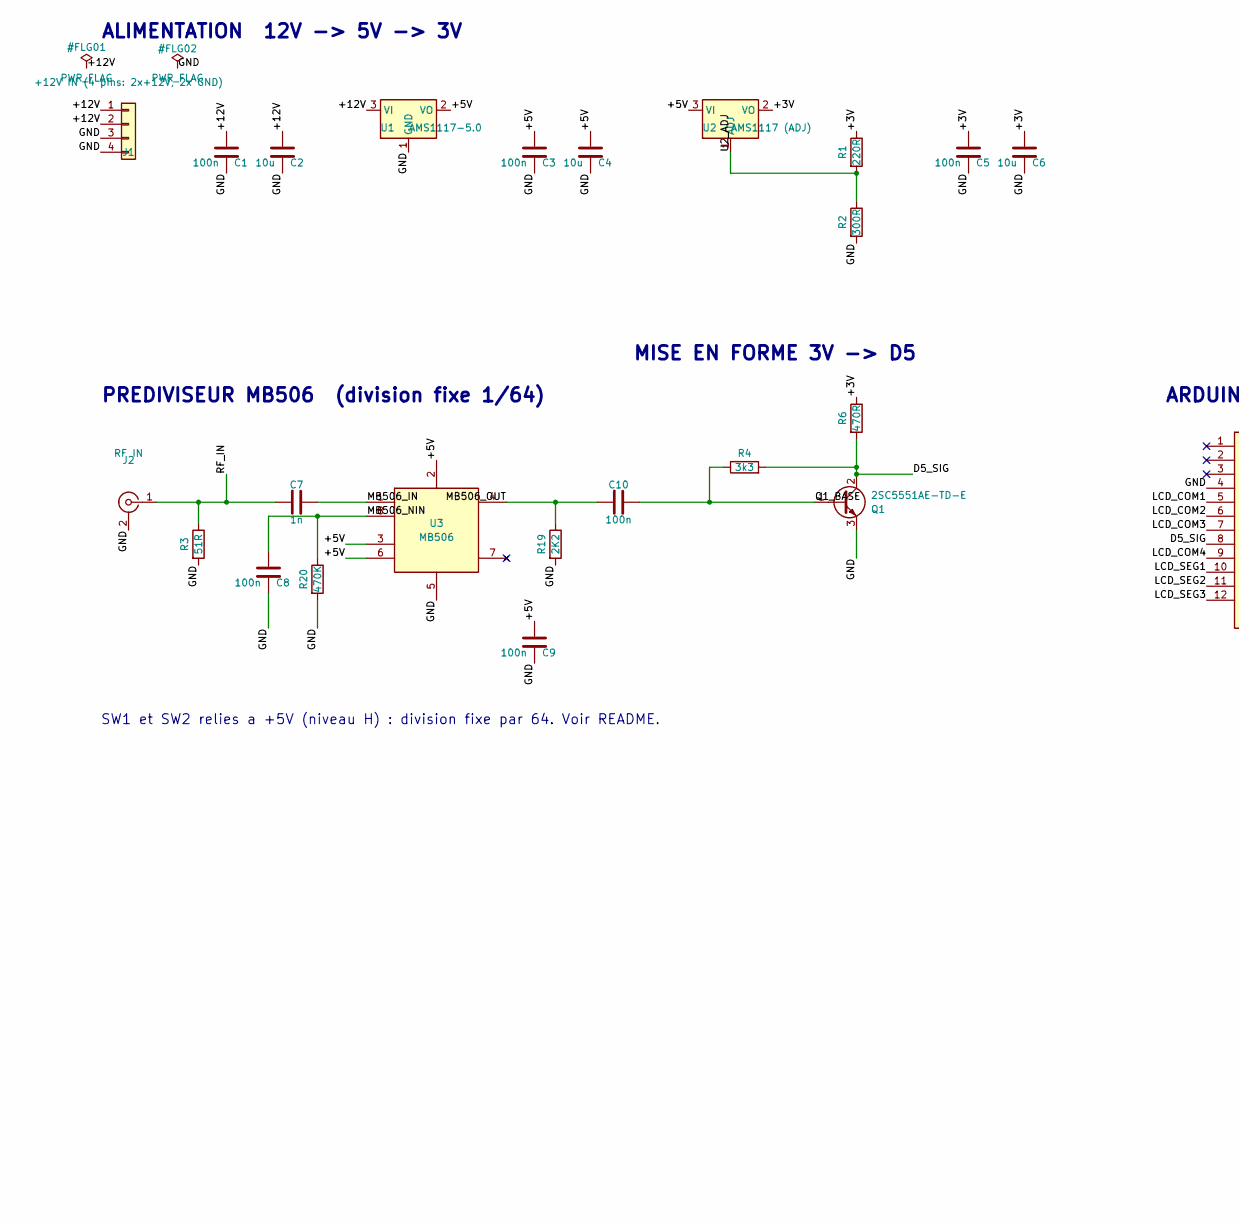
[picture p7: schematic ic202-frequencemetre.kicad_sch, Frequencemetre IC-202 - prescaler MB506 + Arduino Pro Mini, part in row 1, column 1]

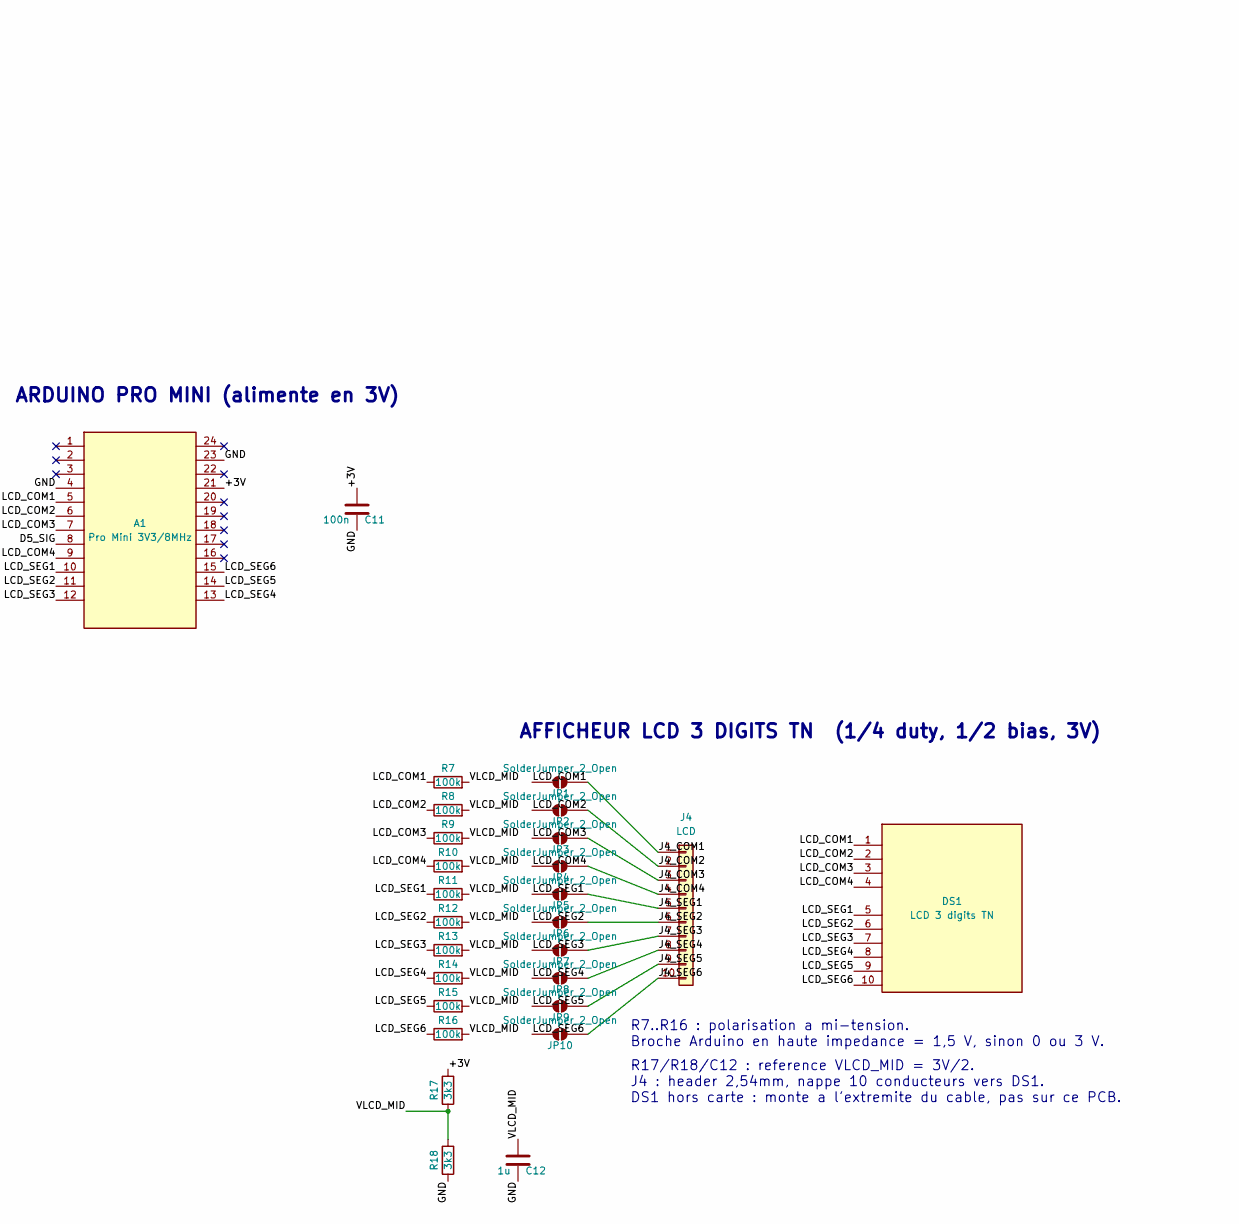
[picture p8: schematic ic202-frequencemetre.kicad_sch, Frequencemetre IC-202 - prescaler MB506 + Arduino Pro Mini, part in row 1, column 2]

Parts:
A1: Pro Mini 3V3/8MHz; Arduino_Pro_Mini_Header_2x12
C1, C3, C5, C8, C9, C10, C11: 100n; C_0603_1608Metric
C2, C4, C6: 10u; C_0805_2012Metric
C7: 1n; C_0603_1608Metric
C12: 1u; C_0805_2012Metric
DS1: LCD 3 digits TN
J1: +12V IN (4 pins: 2x+12V, 2x GND); PinHeader_1x04_P2.54mm_Vertical
J2: RF IN; TestPoint_2Pads_Pitch2.54mm_Drill0.8mm
J4: LCD; PinHeader_1x10_P2.54mm_Vertical
JP1, JP2, JP3, JP4, JP5, JP6, JP7, JP8, JP9, JP10: SolderJumper_2_Open; SolderJumper-2_P1.3mm_Open_Pad1.0x1.5mm
Q1: 2SC5551AE-TD-E; SOT-89-3
R1: 220R; R_0603_1608Metric
R2: 300R; R_0603_1608Metric
R3: 51R; R_0603_1608Metric
R4, R17, R18: 3k3; R_0603_1608Metric
R6: 470R; R_0603_1608Metric
R7, R8, R9, R10, R11, R12, R13, R14, R15, R16: 100k; R_0603_1608Metric
R19: 2K2; R_0603_1608Metric
R20: 470K; R_0603_1608Metric
U1: AMS1117-5.0; SOT-223-3_TabPin2
U2: AMS1117 (ADJ); SOT-223-3_TabPin2
U3: MB506; SOIC-8_5.3x6.2mm_P1.27mm

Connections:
+3V: A1.21 (VCC), C5.1, C6.1, C11.1, R1.1, R6.1, R17.1, U2.2 (VO)
+5V: C3.1, C4.1, C9.1, U1.2 (VO), U2.3 (VI), U3.2 (VCC), U3.3 (SW1), U3.6 (SW2)
+12V: C1.1, C2.1, J1.1, J1.2, U1.3 (VI)
D5_SIG: A1.8 (D5), Q1.2 (C), R4.2, R6.2
GND: A1.4 (GND), A1.23 (GND2), C1.2, C2.2, C3.2, C4.2, C5.2, C6.2, C8.2, C9.2, C11.2, C12.2, J1.3, J1.4, J2.2 (Ext), Q1.3 (E), R2.2, R3.2, R18.2, R19.2, R20.2, U1.1 (GND), U3.5 (GND)
J4_COM1: J4.1, JP1.2 (B)
J4_COM2: J4.2, JP2.2 (B)
J4_COM3: J4.3, JP3.2 (B)
J4_COM4: J4.4, JP4.2 (B)
J4_SEG1: J4.5, JP5.2 (B)
J4_SEG2: J4.6, JP6.2 (B)
J4_SEG3: J4.7, JP7.2 (B)
J4_SEG4: J4.8, JP8.2 (B)
J4_SEG5: J4.9, JP9.2 (B)
J4_SEG6: J4.10, JP10.2 (B)
LCD_COM1: A1.5 (D2), DS1.1 (COM1), JP1.1 (A), R7.1
LCD_COM2: A1.6 (D3), DS1.2 (COM2), JP2.1 (A), R8.1
LCD_COM3: A1.7 (D4), DS1.3 (COM3), JP3.1 (A), R9.1
LCD_COM4: A1.9 (D6), DS1.4 (COM4), JP4.1 (A), R10.1
LCD_SEG1: A1.10 (D7), DS1.5 (SEG1), JP5.1 (A), R11.1
LCD_SEG2: A1.11 (D8), DS1.6 (SEG2), JP6.1 (A), R12.1
LCD_SEG3: A1.12 (D9), DS1.7 (SEG3), JP7.1 (A), R13.1
LCD_SEG4: A1.13 (D10), DS1.8 (SEG4), JP8.1 (A), R14.1
LCD_SEG5: A1.14 (D11), DS1.9 (SEG5), JP9.1 (A), R15.1
LCD_SEG6: A1.15 (D12), DS1.10 (SEG6), JP10.1 (A), R16.1
MB506_IN: C7.2, U3.1 (IN)
MB506_NIN: C8.1, R20.1, U3.8 (~IN)
MB506_OUT: C10.1, R19.1, U3.4 (OUT)
Q1_BASE: C10.2, Q1.1 (B), R4.1
RF_IN: C7.1, J2.1 (In), R3.1
U2_ADJ: R1.2, R2.1, U2.1 (ADJ)
VLCD_MID: C12.1, R7.2, R8.2, R9.2, R10.2, R11.2, R12.2, R13.2, R14.2, R15.2, R16.2, R17.2, R18.1

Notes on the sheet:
PREDIVISEUR MB506 (division fixe 1/64)
SW1 et SW2 relies a +5V (niveau H) : division fixe par 64. Voir README.
AFFICHEUR LCD 3 DIGITS TN (1/4 duty, 1/2 bias, 3V)
ARDUINO PRO MINI (alimente en 3V)
ALIMENTATION 12V -> 5V -> 3V
MISE EN FORME 3V -> D5
R17/R18/C12 : reference VLCD_MID = 3V/2. J4 : header 2,54mm, nappe 10 conducteurs vers DS1. DS1 hors carte : monte a l'extremite du cable, pas sur ce PCB.
R7..R16 : polarisation a mi-tension. Broche Arduino en haute impedance = 1,5 V, sinon 0 ou 3 V.

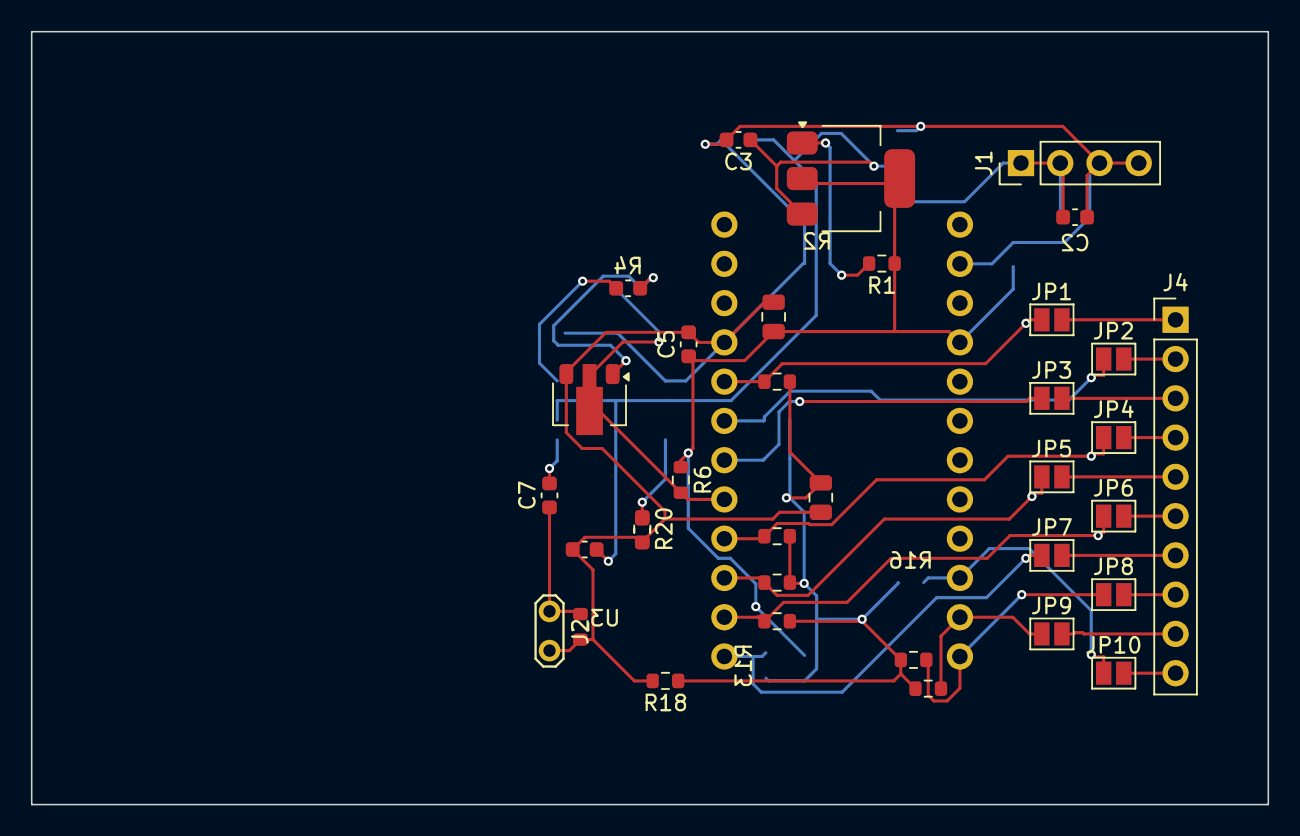
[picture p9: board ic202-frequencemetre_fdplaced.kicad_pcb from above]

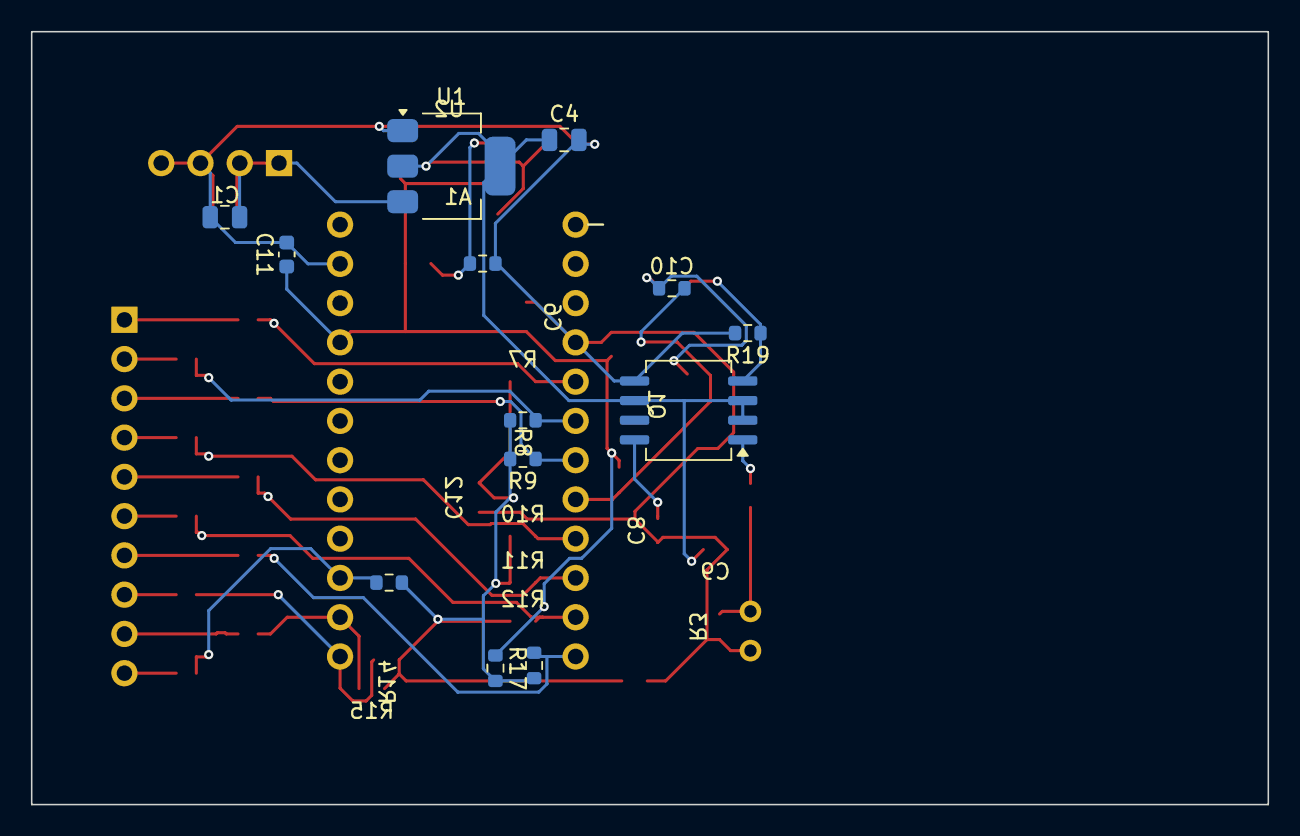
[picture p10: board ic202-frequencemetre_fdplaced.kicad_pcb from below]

Board: 2 copper layers, 80.0 x 50.0 mm, 49 parts (13 on the bottom side), 32 nets.

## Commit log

2026-09-03 Frequencemetre IC-202 : schema KiCad transcrit du schema manuscrit
    Prediviseur MB506 suivi d'un etage a transistor en 3,3 V attaquant D5 d'un
    Arduino Pro Mini, qui pilote un afficheur 3 digits multiplexe.
    Trois symboles crees faute d'equivalent en bibliotheque : MB506, Arduino
    Pro Mini et afficheur 3 digits a cathode commune. Chemin de bibliotheque
    relatif au projet pour que le depot soit clonable.
    ERC sans erreur, netlist verifiee broche a broche. Les valeurs illisibles
    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
    [bom.csv, ic202-frequencemetre.kicad_pcb, ic202-frequencemetre.kicad_sch]
2026-09-03 Modification 1 : rail 3 V et afficheur LCD TN au bout d'une nappe
    La fiche docs/LCD.png montre un afficheur a cristaux liquides TN multiplexe
    en 1/4 duty et 1/2 bias sous 3,0 V, et non un afficheur a LED. Consequences :
    - rail regule ramene de 3,3 V a 3,0 V, R2 passe de 160 R a 140 R ;
    - les 10 broches se repartissent en 4 communs et 6 segments ;
    - les resistances de limitation disparaissent au profit d'une polarisation a
    mi-tension : R7..R16 de 100 k vers VLCD_MID, pont R17/R18 et decouplage C12.
    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
    [bom.csv, ic202-frequencemetre.kicad_sch]
2026-09-03 Modification 2 : corrections de valeurs d'apres le schema relu
    docs/Schema_propre.jpg, une reprise nettement plus lisible du schema
    manuscrit, a permis de corriger plusieurs valeurs mal lues sur la premiere
    photo et de completer un composant manquant :
    - R1 100R->220R, R2 160R->300R (diviseur du LM317L) ;
    - R4 1k->3,3k (base de Q1), R6 1k->470R (collecteur de Q1) ;
    - C8 1n->100n (decouplage de la broche ~IN du MB506) ;
    - R17/R18 10k->3,3k chacune (pont de polarisation du LCD) ;
    - ajout de R19 (2K2), pull-down manquant sur la sortie OUT du MB506,
    visible sur le schema relu et absent de la premiere transcription ;
    - suppression de l'ancien R5 (100k base->GND) et du connecteur J3
    (selecteu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
    [bom.csv, ic202-frequencemetre.kicad_sch]
2026-09-03 Prediviseur MB506 cable en division fixe par 64
    SW1 et SW2 (broches 3 et 6) relies au rail +5V (niveau H), au lieu d'etre
    laisses flottants. D'apres la table du constructeur, SW1=H et SW2=H donnent
    le rapport 1/64.
    C8 deplacee de quelques mm pour degager la rangee des broches SW1/SW2 et
    eviter que les etiquettes +5V ne chevauchent son corps.
    Titre du bloc et note explicative mis a jour en consequence. ERC : 0 erreur,
    0 avertissement. Regles de lisibilite verifiees.
    Claude-Session: https://claude.ai/code/session_017jkpXZgM5sH1vt8JFfAijf
    [ic202-frequencemetre.kicad_sch]
2026-09-03 Correction manuelle de R4 (contre-reaction) + R20 (470k sur pin8 MB506)
    R4 corrigee par l'utilisateur directement dans KiCad : elle relie desormais
    la base au collecteur de Q1 (contre-reaction continue) au lieu d'etre en
    serie entre C10 et la base. Confirmee par lecture du fichier sur disque
    avant toute modification.
    Ajout de R20 (470k) entre la broche 8 (~IN) du MB506 et GND, placee a cote
    de C8 comme demande. C'etait le reseau visible sur le schema relu dont
    l'extremite restait ambigue ; il polarise l'entree complementaire vers la
    masse pour un pilotage en simple extremite.
    Replacement de C8 et R20 en colonne verticale (plutot que cote a cote) pour
    eviter le chevauchement de leurs etique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
    [bom.csv, ic202-frequencemetre.kicad_sch]
2026-09-04 J2 : mini coaxial soude sur 2 pastilles plutot qu'un connecteur SMA
    Remplacement de l'empreinte Connector_Coaxial:SMA_Amphenol_132289_EdgeMount
    par TestPoint:TestPoint_2Pads_Pitch2.54mm_Drill0.8mm : deux pastilles
    traversantes (pas 2,54 mm, percage 0,8 mm) pour souder directement l'ame et
    le blindage d'un mini cable coaxial, sans connecteur SMA monte.
    Numerotation des pastilles verifiee via pcbnew (1=IN, 2=Ext), coherente
    avec le symbole Connector:Conn_Coaxial deja en place ; aucune modification
    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
    [bom.csv, ic202-frequencemetre.kicad_sch]
2026-09-04 J4 : header 2,54mm ; DS1 marque hors carte (monte au bout du cable)
    J4 : empreinte remplacee par un header 1x10 P2.54mm vertical
    (Connector_PinHeader_2.54mm:PinHeader_1x10_P2.54mm_Vertical), a la place
    du connecteur JST-SH 1mm.
    DS1 : on_board mis a "no". L'afficheur reste dans le schema et la BOM pour
    documenter le systeme complet, mais sync_schematic_to_board ne lui creera
    pas d'empreinte sur ce PCB puisqu'il est monte a l'extremite du cable, pas
    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
    [bom.csv, ic202-frequencemetre.kicad_sch]
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2026-09-04 Empreinte de A1 : montage sur picots, courtyards des 2 headers uniquement
    Le Pro Mini est branche sur deux barrettes de picots femelles, en surelevation
    du PCB principal, pour liberer le volume sous le module au profit d'autres
    composants. Nouvelle empreinte IC202:Arduino_Pro_Mini_Header_2x12 : 24
    broches (2x12, pas 2,54mm, 15,24mm entre rangees), avec un courtyard separe
    par rangee - aucun contour de carte complet, aucun courtyard englobant tout
    le module, pour ne pas signaler ce volume comme occupe.
    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
    [bom.csv, ic202-frequencemetre.kicad_sch]
2026-09-04 Renomme la bibliotheque d'empreintes IC202.pretty -> frequencemetre.pretty
    Dossier .pretty et nickname fp-lib-table renommes ensemble (le nickname
    suivait le nom du dossier par convention). Reference "Footprint" mise a jour
    aux trois endroits : lib_symbols embarque du schema, instance A1, et
    bibliotheque de symboles IC202.kicad_sym.
    La bibliotheque de symboles (IC202.kicad_sym / sym-lib-table, nickname
    IC202) n'est pas concernee, seule la bibliotheque d'empreintes changeait
    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
    [bom.csv, ic202-frequencemetre.kicad_sch]
2026-09-04 Documente l'intention de conception via la propriete Placement
    Applique le skill conception-electronique-kicad au schema existant :
    propriete masquee Placement posee sur chaque composant dont la position
    finale importe au-dela du raccordement electrique.
    Decouplage documente (prefixe LOCAL) : C1/C2 (entree J1, IN de U1), C3/C4
    (noeud partage OUT U1 / VI U2), C5/C6 (sortie U2), C9 (VCC de U3), C8 (~IN
    de U3, decouplage HF sur broche signal - pas une broche d'alimentation),
    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
    [ic202-frequencemetre.kicad_sch]
2026-09-04 Regulateurs en CMS : L7805->AMS1117-5.0, LM317L->AMS1117 ajustable
    Stock PartsBox de l'utilisateur consulte avant de figer le choix (suivant
    le skill conception-electronique-kicad) : ni L7805 ni LM317L en CMS en
    stock, mais AMS1117-5.0 (68), AMS1117 ajustable (10) et AMS1117-3.3 (71)
    en SOT-223, tous chez le meme fournisseur de stockage (C3 small
    regulators). Choix retenu par l'utilisateur : AMS1117-5.0 pour U1,
    AMS1117 ajustable pour U2 - topologie inchangee (meme reference 1,25V que
    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
    [bom.csv, ic202-frequencemetre.kicad_sch]
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2026-09-05 U3->SOP-8, Q1->SOT-89, J1->4 broches ; cavaliers devant J4 ; replacement 80x50mm
    Schema :
    - U3 (MB506) : DIP-8 -> SOP-8 (MB506PF Fujitsu, stock PartsBox), meme
    brochage 1-8, pas de changement de symbole.
    - Q1 : 2N2369 (TO-18) -> 2SC5551AE-TD-E (onsemi, SOT-89, fT=3.5GHz, stock
    PartsBox). Symbole remplace par Q_NPN_BCE (meme geometrie de broches que
    Q_NPN_BEC, seul l'etiquetage broche/fonction change) pour correspondre au
    brochage reel du SOT-89 (broche 2 = collecteur sur la languette).
    - J1 : connecteur 2 broches -> 4 broches, paires adjacentes 1-2=+12V et
    3-4=GND. Corrige au passage un bug preexistant (les 2 broches d'origine
    et leurs labels +12V/GND etaient orphelins, non relie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
    [bom.csv, ic202-frequencemetre.kicad_pcb, ic202-frequencemetre.kicad_sch]
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2026-09-05 Corrige un court-circuit entre lignes LCD introduit par le routage des cavaliers
    Les 10 fils cavalier->J4 passaient par un coude a abscisse commune
    (x=330.2). Les pas differents cote resistances (5,08mm) et cote J4
    (2,54mm) faisaient que plusieurs segments verticaux se chevauchaient sur
    cette abscisse, court-circuitant COM2-COM3-COM4-SEG1 d'un cote et
    SEG3-SEG4 de l'autre. Trouve en tentant un premier routage (l'ERC ne
    signalait qu'un avertissement discret, pas une erreur).
    Corrige : les 10 chemins coudes remplaces par un fil diagonal unique par
    ligne (aucun point partage entre lignes differentes). Chaque broche de J4
    recoit aussi un label explicite (J4_COM1..J4_SEG6) : sync_schematic_to_bo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
    [ic202-frequencemetre.kicad_pcb, ic202-frequencemetre.kicad_sch]
2026-09-05 Premier routage complet : 0 erreur DRC
    Autoroutage Freerouting (2 couches) sur le placement manuel : 16,5s,
    278 pistes + 29 vias. 11 pistes exportees a 0,15mm par le pipeline
    KiCad->DSN->Freerouting (la carte impose 0,2mm min, limitation connue et
    reproductible du pipeline) corrigees une par une (piste supprimee puis
    retracee a 0,2mm au meme endroit).
    Comparaison de placement tentee avec l'outil externe FD-Autoplacer
    (optimisation par descente de gradient) : resultat non retenu
    (chevauchement de courtyard reel, composants debordant du bord de carte).
    Le placement manuel a ete conserve ; fichier d'experimentation exclu du
    depot (kicad/fd-autoplacer-experiment/, non commite).
    run_drc final :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
    [ic202-frequencemetre.kicad_pcb]
2026-09-05 Corrige 5 broches actives sans net (bug critique non detecte par ERC/DRC)
    Trouve via inspection visuelle : la broche 1 de U3 semblait connectee a
    trop d'endroits. Cause reelle : 5 nets sans label explicite (Net-(U3-IN),
    Net-(U3-OUT), Net-(U3-~{IN}), Net-(Q1-B), Net-(U2-ADJ)) - valides au
    schema, ERC silencieux - mais que sync_schematic_to_board echoue a
    resoudre, laissant ces broches sans net du tout cote PCB. Consequence
    reelle : la sortie du prescaler U3 et la base de Q1 n'ont jamais ete
    reliees a la chaine de comptage, sur aucune des deux cartes, malgre un DRC
    a 0 erreur (une broche sans net n'a aucune obligation de clearance envers
    les autres nets).
    Corrige :
    - 5 nets renommes explicite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
    [ic202-frequencemetre.kicad_pcb, ic202-frequencemetre.kicad_sch]
2026-09-06 Verse fd-autoplacer-experiment sous suivi git
    Retire l'exclusion de kicad/fd-autoplacer-experiment/ (jusqu'ici marque
    "non retenu") : les deux boards (placement manuel et FD-Autoplacer) vont
    etre ameliores en parallele. Corrige aussi les 4 regles .gitignore qui
    ne visaient que kicad/*.ext (racine) pour qu'elles s'appliquent aussi aux
    sous-dossiers (kicad/**/*.ext), afin que les fichiers intermediaires
    Freerouting (.dsn/.ses) et le rapport de violations DRC du board
    fd-placed restent bien ignores comme pour la carte principale.
    Etat verse : ic202-frequencemetre_fdplaced.kicad_pcb/.kicad_pro,
    0 erreur DRC (voir session precedente : 23 rotations optimisant le
    ratsnest + reroutage complet).
    Co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
    [ic202-frequencemetre_fdplaced.kicad_pcb]
2026-09-06 fd-placed : ajustements manuels de placement et routage
    Etat verse tel que laisse par l'utilisateur apres ses propres retouches de
    placement/routage dans l'editeur KiCad (en parallele du travail d'autoroutage
    et de correction DRC mene cote agent sur ce meme board).
    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
    [ic202-frequencemetre_fdplaced.kicad_pcb]
2026-09-07 Corrige fp-lib-table fd-placed et reroute; ajoute doc LCD
    - kicad/fd-autoplacer-experiment/fp-lib-table (nouveau) : enregistre la
    bibliotheque locale "frequencemetre" pour ce sous-projet (jusqu'ici
    invisible faute de fp-lib-table propre a ce dossier -> warning DRC
    "does not include the footprint library 'frequencemetre'").
    - fd-placed : reload + effacement + reautoroutage complet (32/32 nets)
    apres application de la correction ci-dessus ; verifie via
    find_wrong_face_stubs.py (0 piste mal orientee). Les etiquettes de face
    incoherentes (lib_footprint_mismatch, 22 cas) etaient deja resolues par
    une sauvegarde depuis l'editeur KiCad entre-temps.
    - kicad/frequencemetre.pretty/Arduin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
    [ic202-frequencemetre.kicad_pcb, ic202-frequencemetre_fdplaced.kicad_pcb]
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2026-09-18 Compacte le PCB : alim descendue, carte recoupee a 60 x 50 mm
    Le contour 60 x 80 mm etait un point de depart a reduire, pas un cadre a
    respecter : la colonne gauche avait 31,5 mm de hauteur totalement vide
    (y 27,0 -> 58,5) entre la fin de l'alimentation et le debut de la partie RF.
    - J1, U1, U2, C1-C6, R1 et R2 descendus de 23,67 mm en bloc : le haut de
    J1 est desormais exactement au niveau du haut de JP10 (y 1,82 mm)
    - contour recoupe en haut et en bas : 60 x 50 mm au lieu de 60 x 80 mm,
    soit 1200 mm2 de carte economises ; la largeur est inchangee
    - toute la geometrie translatee de -26 mm pour ramener la carte a
    l'origine ; plans de masse et vias de couture reverses sur le nouveau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
    [ic202-frequencemetre.kicad_pcb]
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
